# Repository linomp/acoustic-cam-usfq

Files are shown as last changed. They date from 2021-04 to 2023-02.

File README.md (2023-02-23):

# Sound Visualization with an Acoustic Camera

This is the source code repository for the project "Sound Visualization with an Acoustic Camera", my Mechanical Engineering undergraduate thesis at USFQ (Ecuador).

The thesis explains the process of building an [acoustic camera](https://felixtrument.ca/acoustic-camera-all-you-need-know/), from the design of the microphone array to the integration of the required software layers. 

A National Instruments data acquisition card and LabView were used to record the signals of an array of 16 condenser microphones simultaneously, while the open source library [Acoular](http://www.acoular.org/) was used to process the signals, applying beamforming techniques. 

The result was a prototype of an acoustic camera capable of distinguishing and characterizing static sound sources in a frequency range from 2.8 kHz up to 6 kHz. 

## Resources
- [Download the full thesis here](https://repositorio.usfq.edu.ec/handle/23000/8978)
- [Check the project poster](https://github.com/linomp/acoustic_cam_usfq/blob/master/Poster.pdf)

## Index

1. [Installation](https://github.com/linomp/acoustic_cam_usfq#1-installation)
2. [Testing](https://github.com/linomp/acoustic_cam_usfq#2-testing)
3. [Performing new measurements](https://github.com/linomp/acoustic_cam_usfq#3-performing-new-measurements)
4. [Notes](https://github.com/linomp/acoustic_cam_usfq#4-notes)

## 1. Installation

### Python & Acoular
- [Anaconda with Python 3 support](https://www.anaconda.com/products/individual)
- [The acoular library (version 19)](https://pypi.org/project/acoular/19.2/)

  Make sure you go through their `Installation` and `Getting Started` sections to verify your installation is correct.
    
    After going through the [installation described here](http://www.acoular.org/install/index.html), you should be able to open the Anaconda prompt, type `python` to open the python interpreter, paste the following commands:
    
    ```python
    import acoular
    acoular.demo.acoular_demo.run()
    ```
    and you should get this result:
    
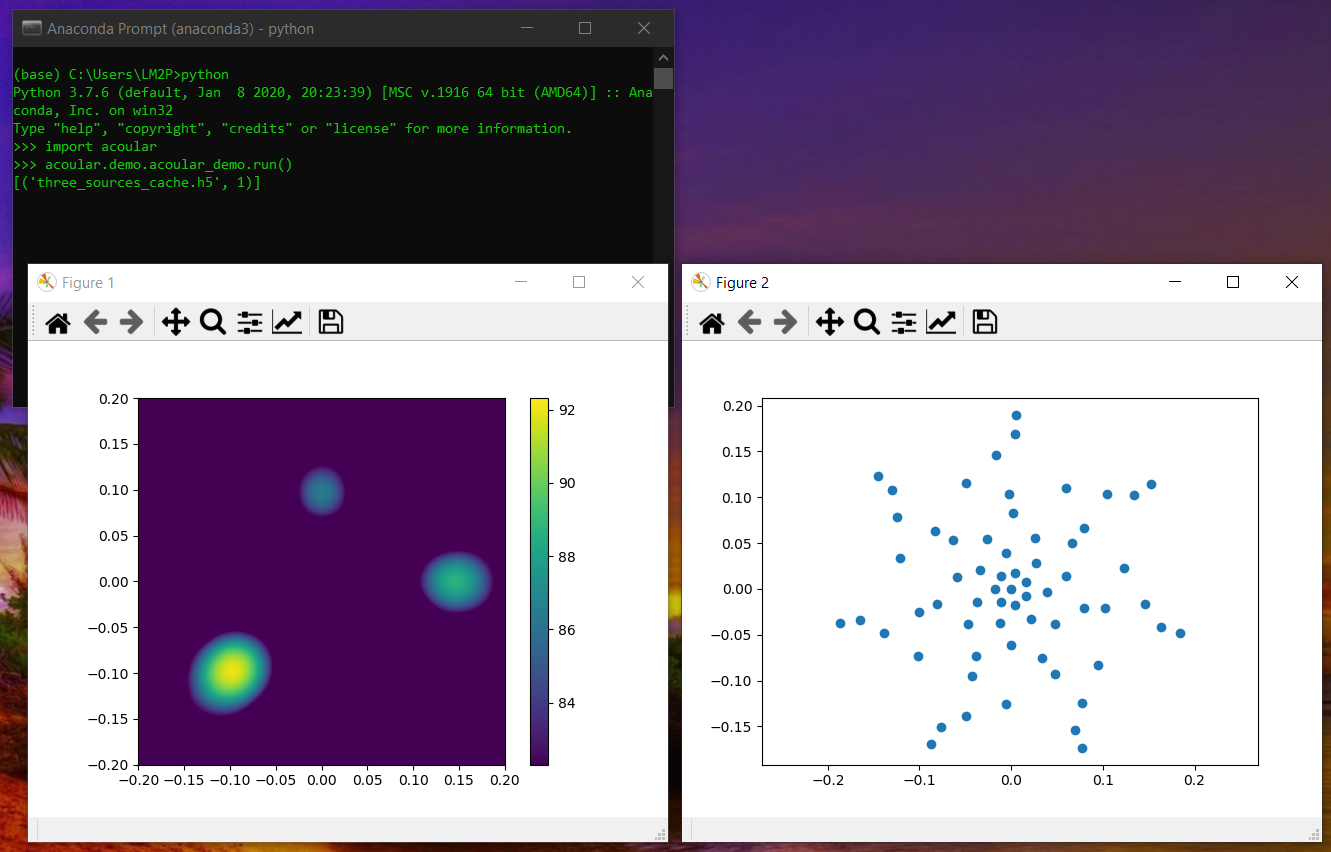
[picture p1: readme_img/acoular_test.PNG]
  

### LabView 
- [LabView 2017 SP1](https://www.ni.com/it-it/support/downloads/software-products/download.labview.html#306359) 
  - Note: uncheck the VI Package Manager 2017 option. You will be installing the latest version directly from their website, which works better.  
- [VI Package Manager (VIPM)](https://www.vipm.io/download/)
  - Note: after installing, hit the button that looks like a "refresh" icon to update the package repository so VIPM will work correctly.   

### LabView Packages
It is recommended to install these packages with VIPM, **in this exact order**:
- [OpenG Libraries](https://www.vipm.io/package/openg.org_lib_openg_toolkit/)   
- [LiveHDF by UPVI](https://www.vipm.io/package/lvhdf5/) ([documentation](http://www.upvi.net/main/index.php/products/lvhdf5))

At this point, your installed package listing should contain at least all these:

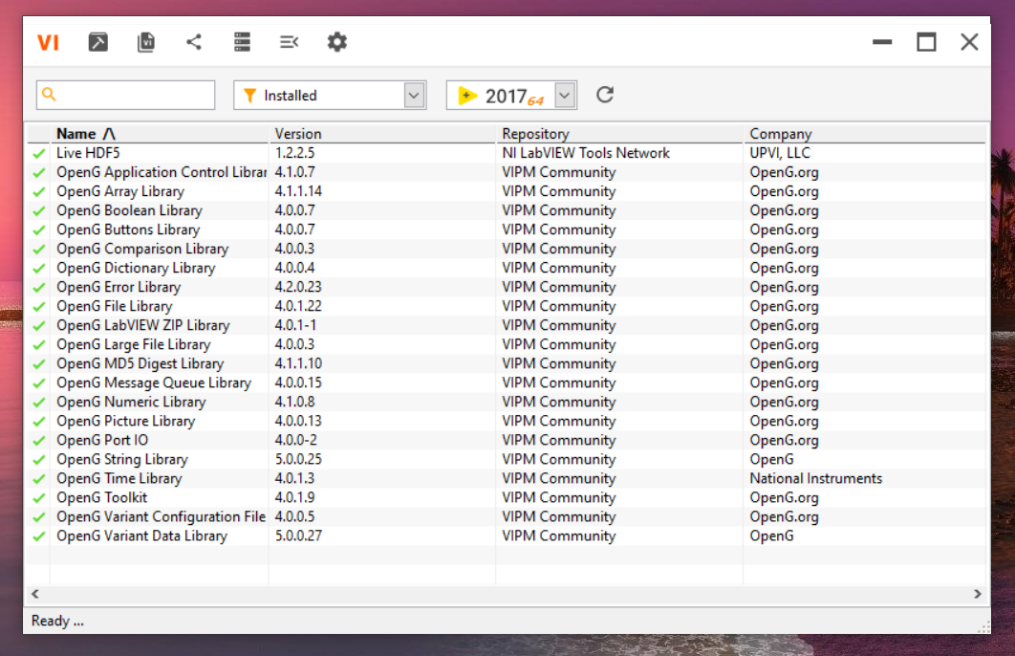
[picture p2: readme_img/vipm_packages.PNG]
  

These ones are installed from outside VIPM:
- [VAS](https://www.ni.com/en-us/support/downloads/drivers/download.vision-acquisition-software.html#367318) for LabView to webcam interfacing
- [NI DAQmx](https://www.ni.com/en-us/support/downloads/drivers/download.ni-daqmx.html#348669) for microphone data acquisition

### Optional tools
- [HDFView](https://www.hdfgroup.org/downloads/hdfview/) to inspect HDF5 files of your audio recordings and their metadata.
  - Note: If the program fails to launch, [try the solution mentioned here](https://portal.hdfgroup.org/display/support/HDFView+3.1.2#HDFView3.1.2-knownprobs). 
   
    To make the HDFViewApp-3.1.2 work on Windows 10 (64 bits), they ask you to download and paste the `hdfview.bat` file here:

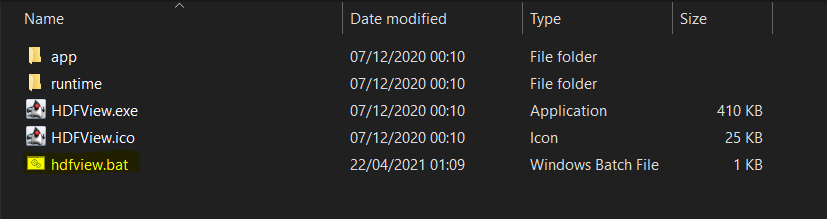
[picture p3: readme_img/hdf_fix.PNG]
      

    Then the app can be opened by double clicking on that `hdfview.bat` file.

## 2. Testing

To test your environment, an example measurement is provided. This includes an image and a white-noise recording in an hdf5 file.

- Open the project **`development_version/Beamforming_0_0_1.lvproj`**. In there open the VI called **`BeamformerGUI_GivenFreqs.vi`** and execute it.

- Switch from the `Measurement` tab to the `Processing` tab.
  
  - The Python server should be started in the background, give it some time. When the VI is ready to perform an analysis, it looks like this:
  
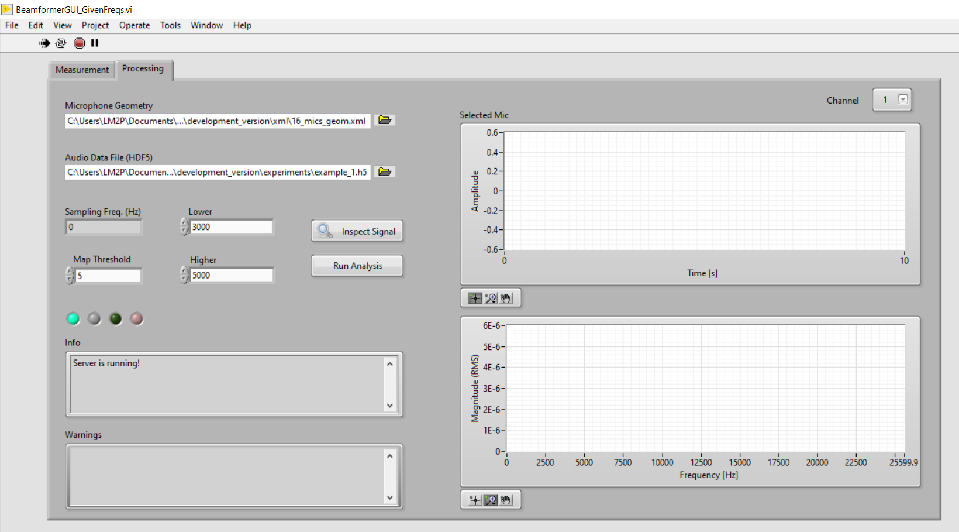
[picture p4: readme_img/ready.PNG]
     

  - By default, the VI already searches for the microphone geometry file `16_mics_geom.xml` in the `development_version/xml` folder. If you ever need to include another microphone geometry file, that is the place to add it.

  - For the `Audio Data File (HDF5)` option, make sure it points to: `development_version/experiments/example_1.h5` (should be done by default too, but please double check).
  
    - Inspecting it with HDFView:
    
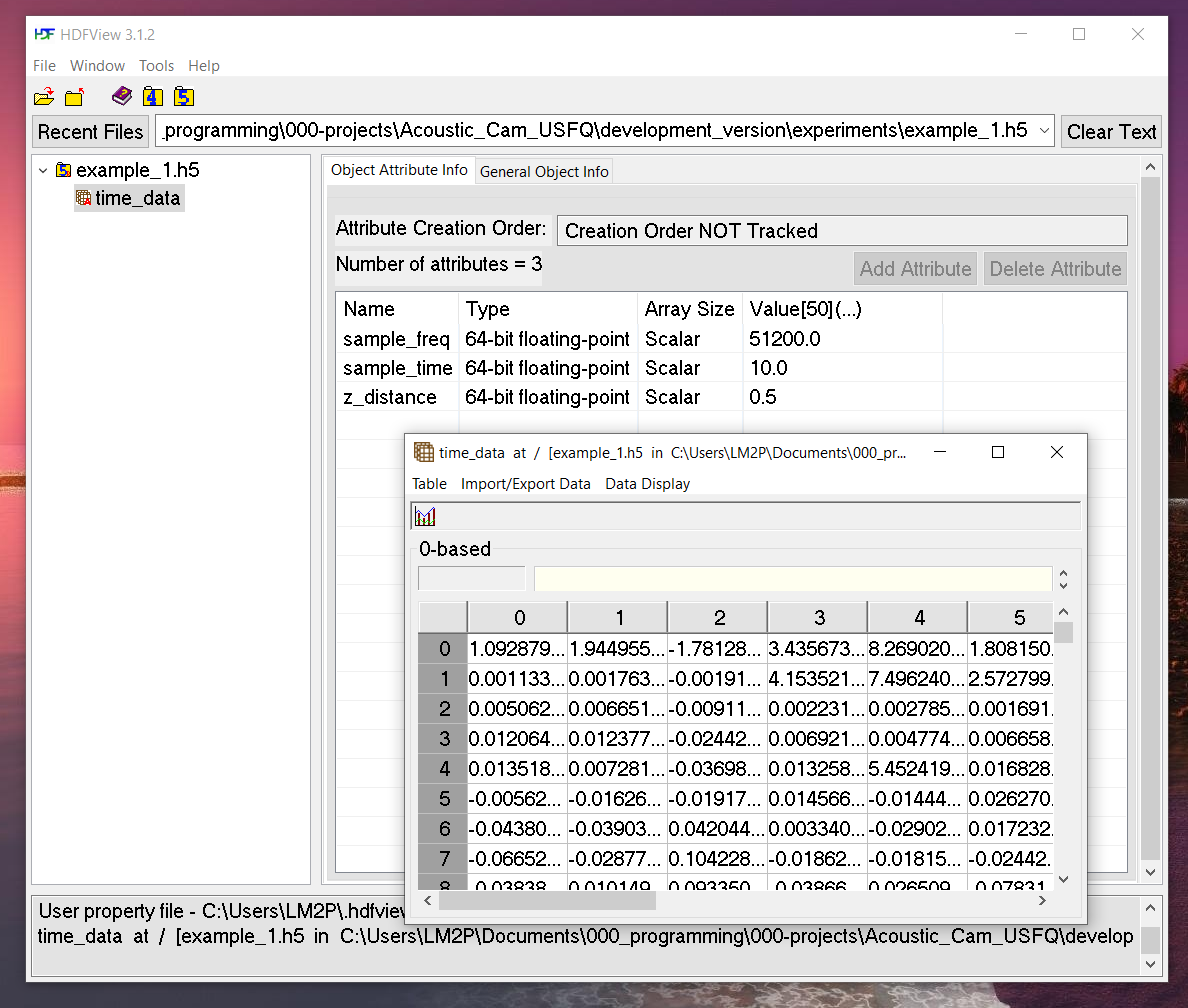
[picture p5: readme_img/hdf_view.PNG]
      
    
    - Inspecting it with the `Inspect Signal` function:
  
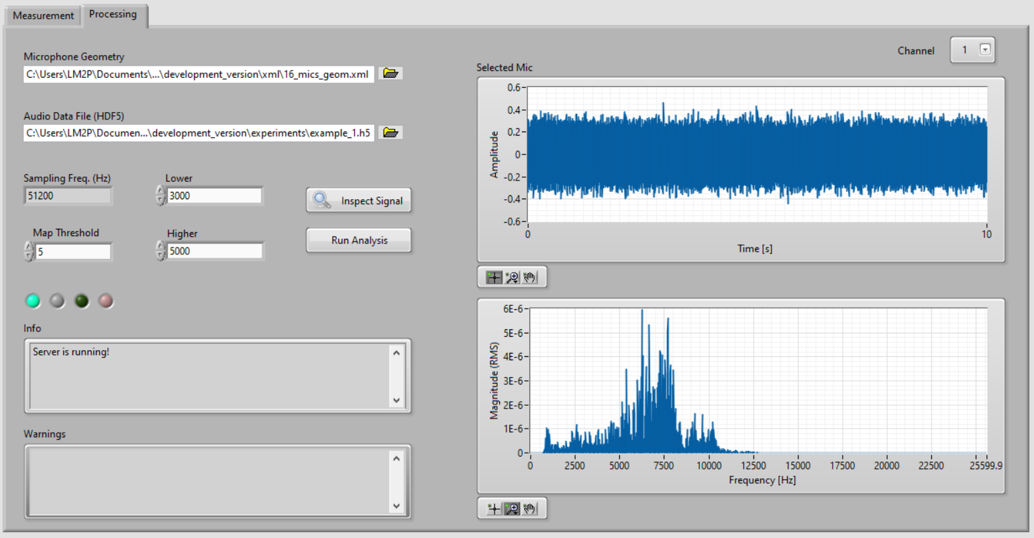
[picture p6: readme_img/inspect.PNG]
      

    - Click on `Run Analysis` and you should get this message:
  
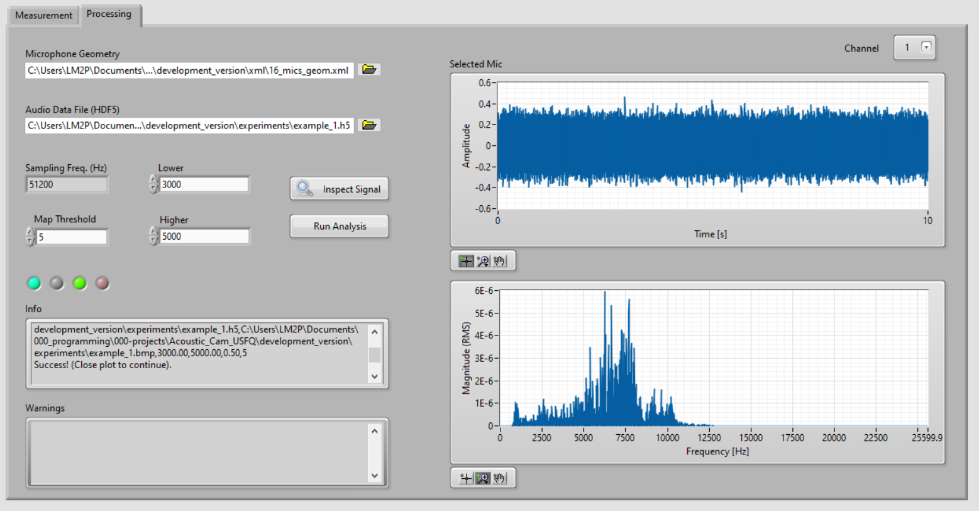
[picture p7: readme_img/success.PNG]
      

      And the following plot:

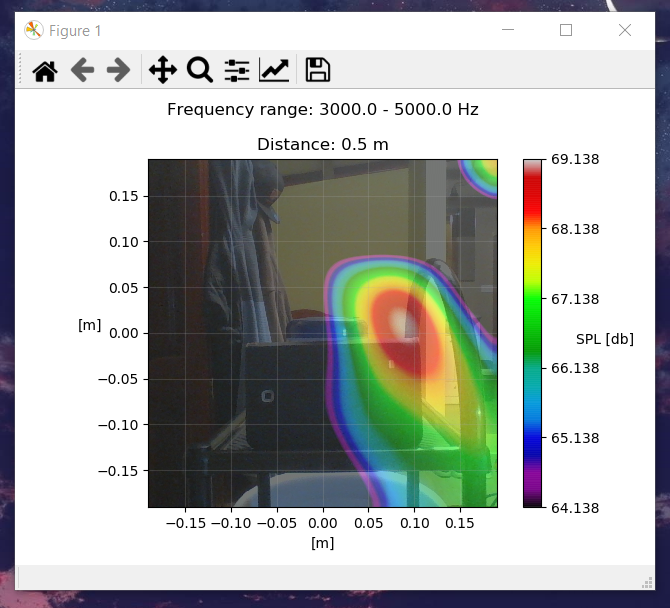
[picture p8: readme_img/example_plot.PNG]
      

## 3. Performing New Measurements

**Tip:** read the [Final Report](https://github.com/linomp/acoustic_cam_usfq/blob/master/Final%20Report.pdf) for information about best-performing parameters.

- In the `Measurements` tab, you can use the `Preview Signals` button to check the status of the microphones:

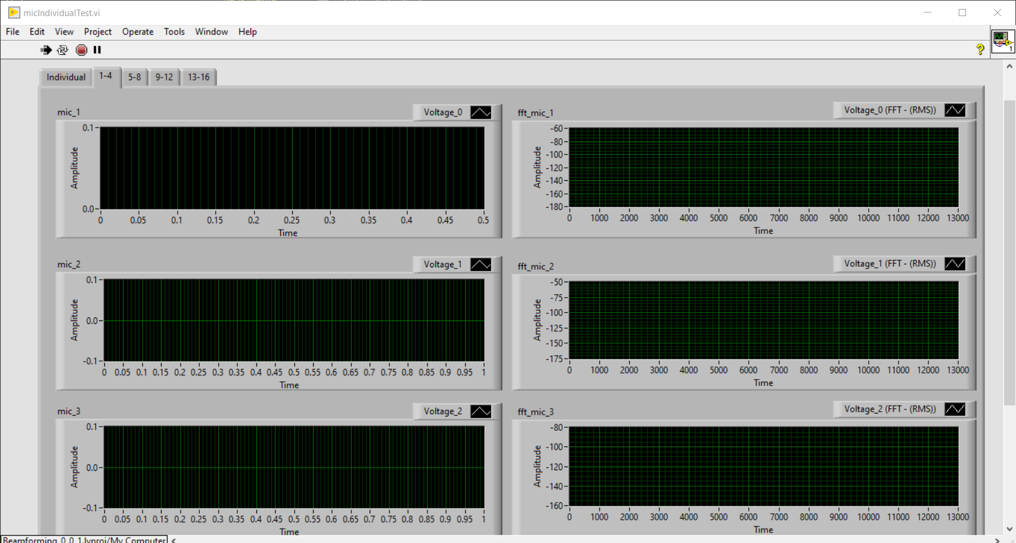
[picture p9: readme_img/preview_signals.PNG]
  

- Select the camera device.
- Focus the camera to the desired object/scenario to analyze.
- Select the data directory.
- Input a name for the experiment (will be used both for the audio recording and the image).  
- Input the distance in [m] from the array to the sound source.
- Input a sampling time and a sampling frequency. 
  - Note: Take into account that the hardware has its sampling rate limitations. Also, theoretically the sampling frequency has to be at least twice the maximum frequency in the signal you wish to analyze (see [Nyquist Theorem](http://microscopy.berkeley.edu/courses/dib/sections/02Images/sampling.html) / [Recommended Video](https://www.youtube.com/watch?v=yWqrx08UeUs)).  
- Click record and wait.
- After recording, the GUI should look like this:
  
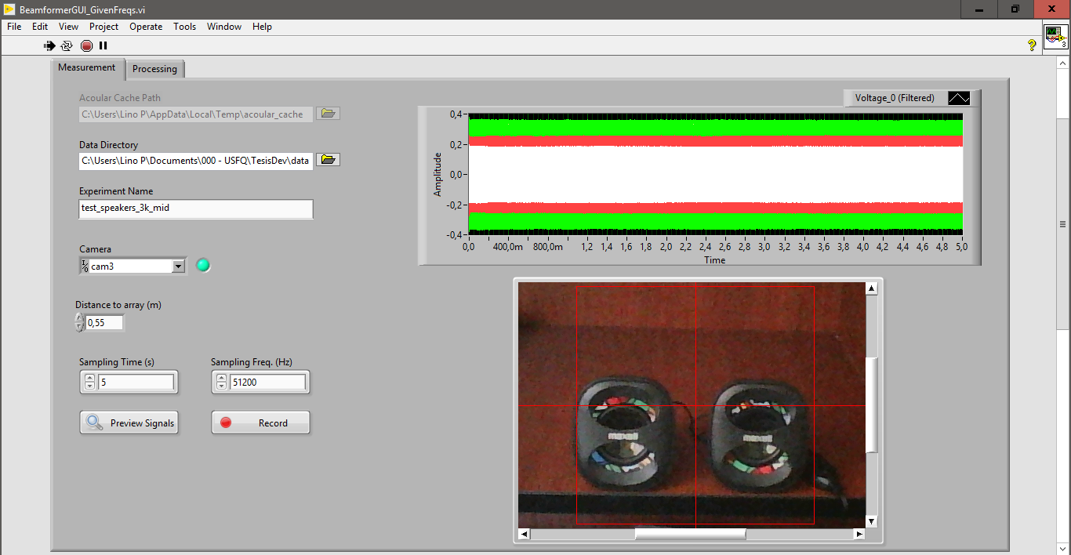
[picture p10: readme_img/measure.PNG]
   

- Switch to the `Processing` tab. It will already be pointing to the newly created data file. There you can `Inspect` the signal or `Run   Analysis` immediately, like in the previous section.

- The `Lower` and `Higher` parameters determine the beggining and start of the frequency range to be taken into account for the actual acoustic map.

## 4. Notes
- The VI measurement feature cannot be performed without the Data Acquisition board already connected and configured.  

- There might be setup and or additional driver installation required when connecting the Data Acquisition board. 
  
  Locate this section of the `BeamformerGUI_GivenFreqs.vi` block diagram and open the `DAQ Assistant` to configure your hardware:

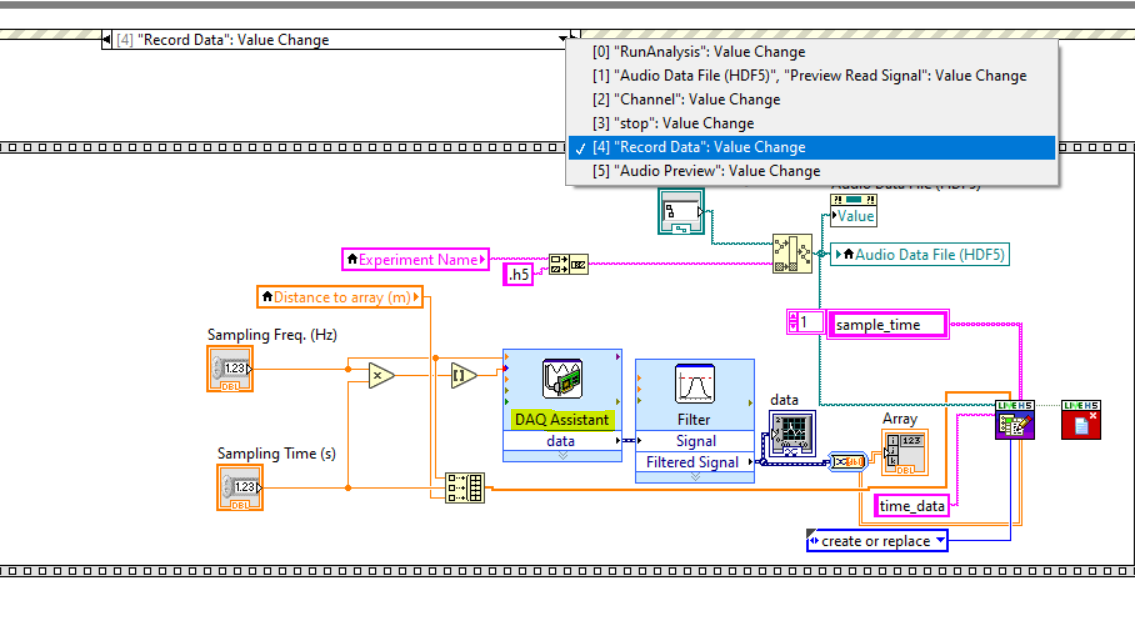
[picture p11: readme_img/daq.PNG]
   

- The calibration file location is currently `/development_version/xml/ECM8000_07_09_19_01.xml` and this is hard-coded in the `development_version/py/beamforming.py` file. Take this into account if you need to provide a different file.

- Take note of the `Acoular Cache Path` in the `Measurement` tab. Acoular saves previous results there to optimize performance but you might need to manually clear the contents of that folder if you want to analyze new measurements with a same filename you used previously.

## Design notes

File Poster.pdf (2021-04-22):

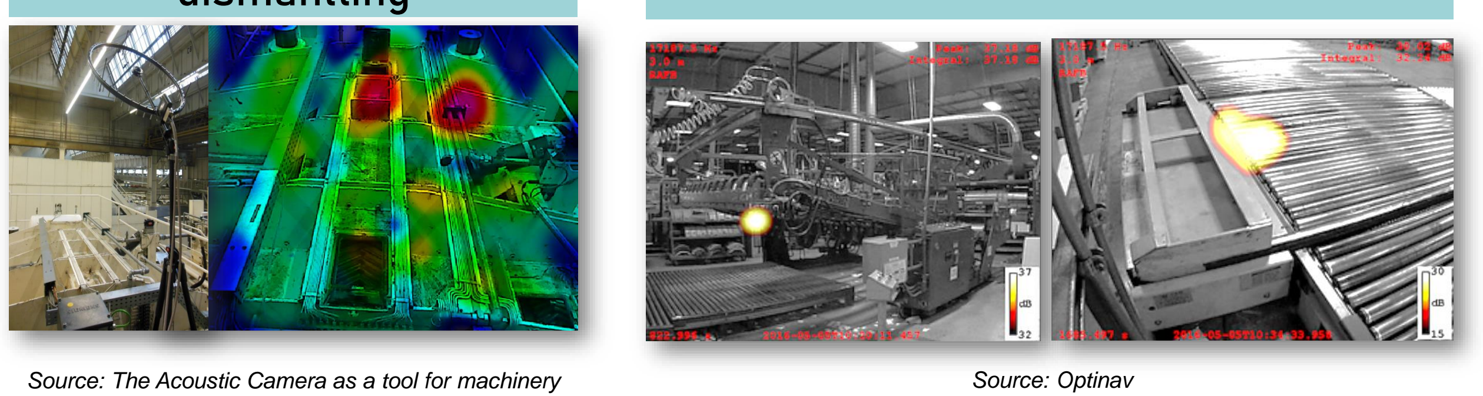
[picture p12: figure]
Source: Optinav
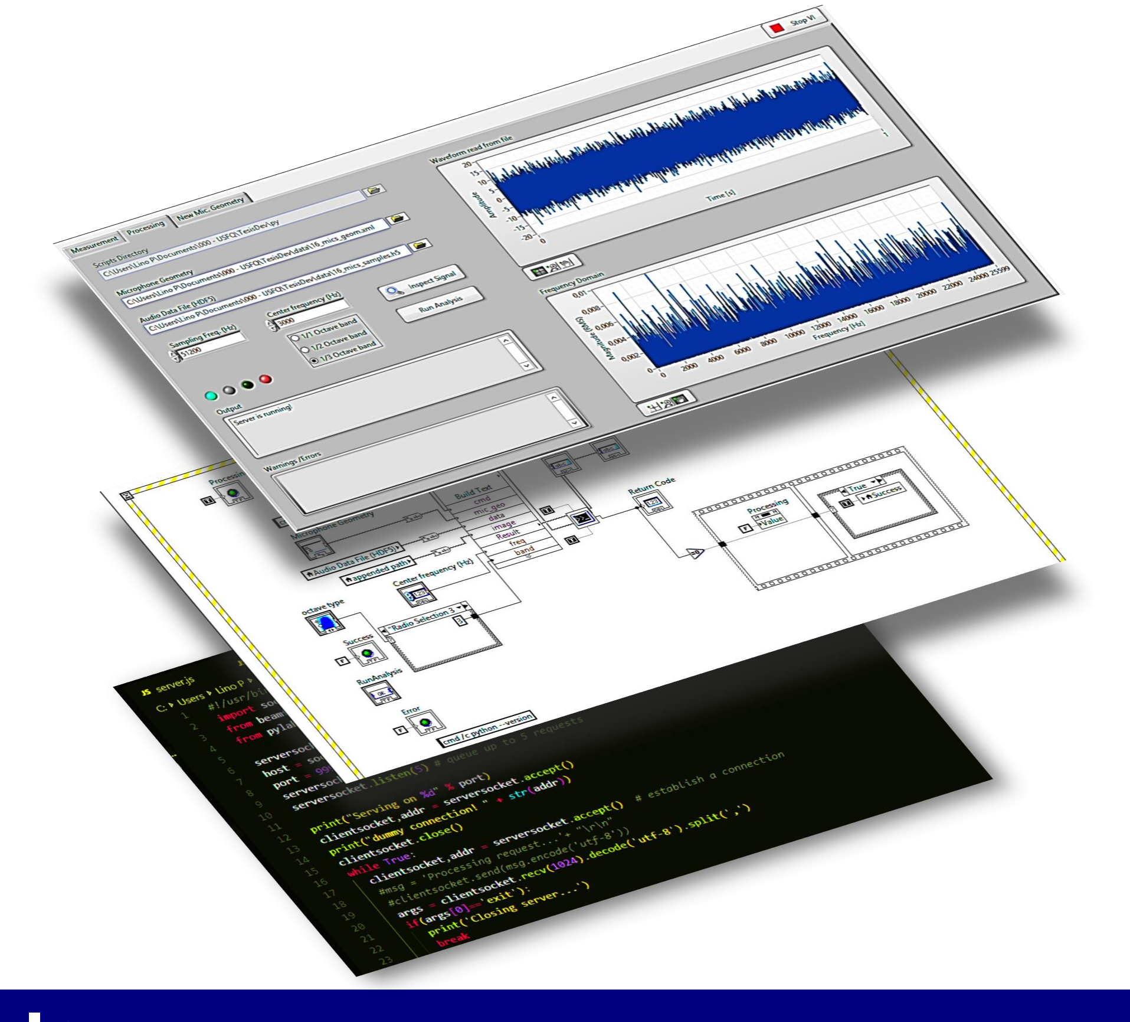
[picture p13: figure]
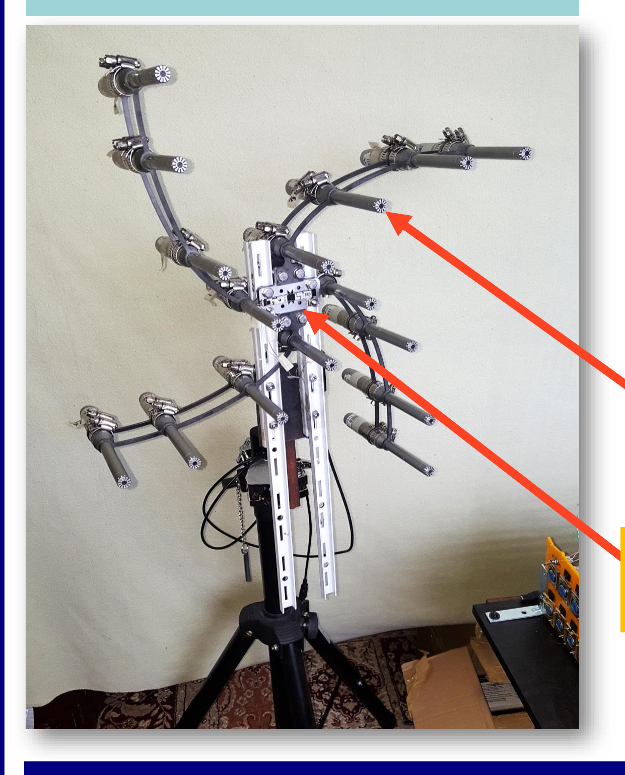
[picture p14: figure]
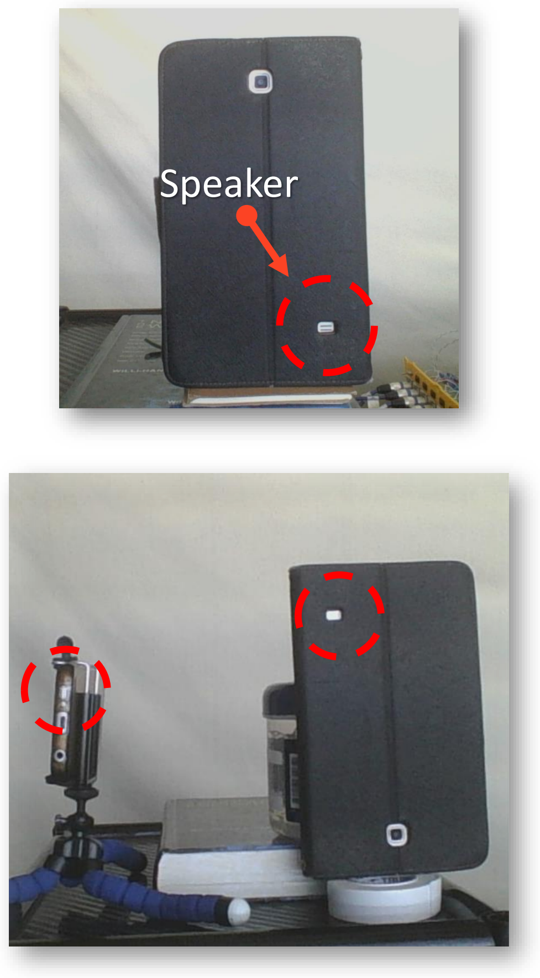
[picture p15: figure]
Speaker
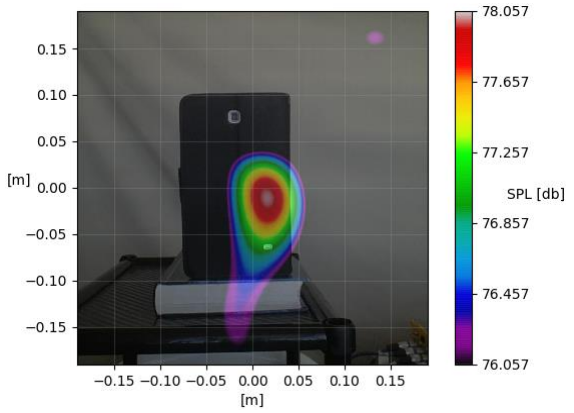
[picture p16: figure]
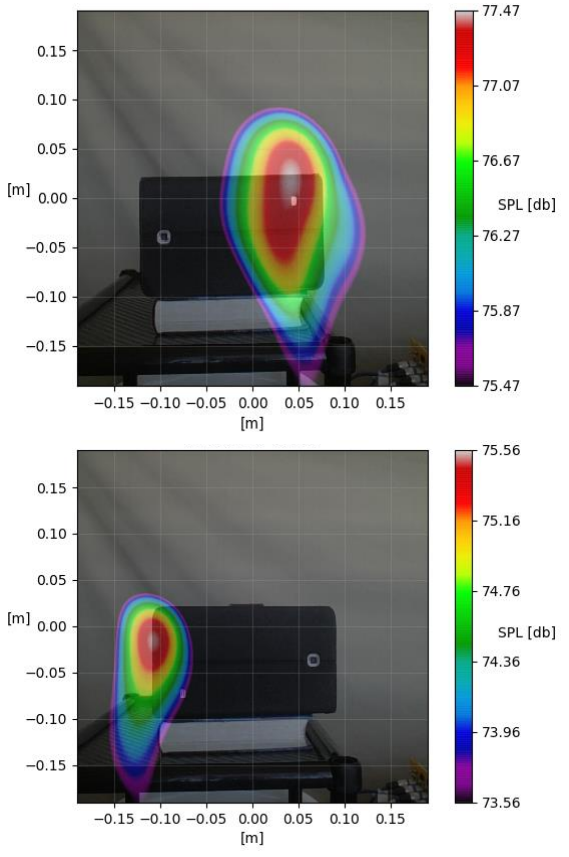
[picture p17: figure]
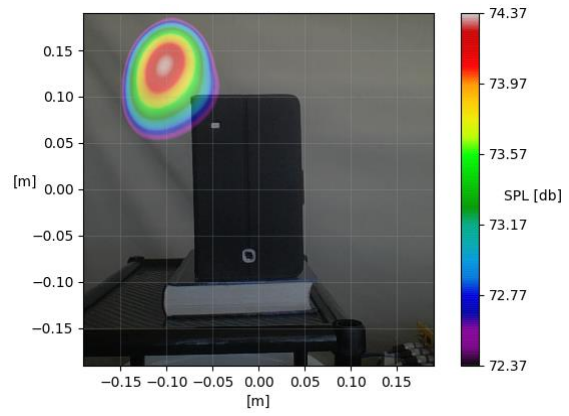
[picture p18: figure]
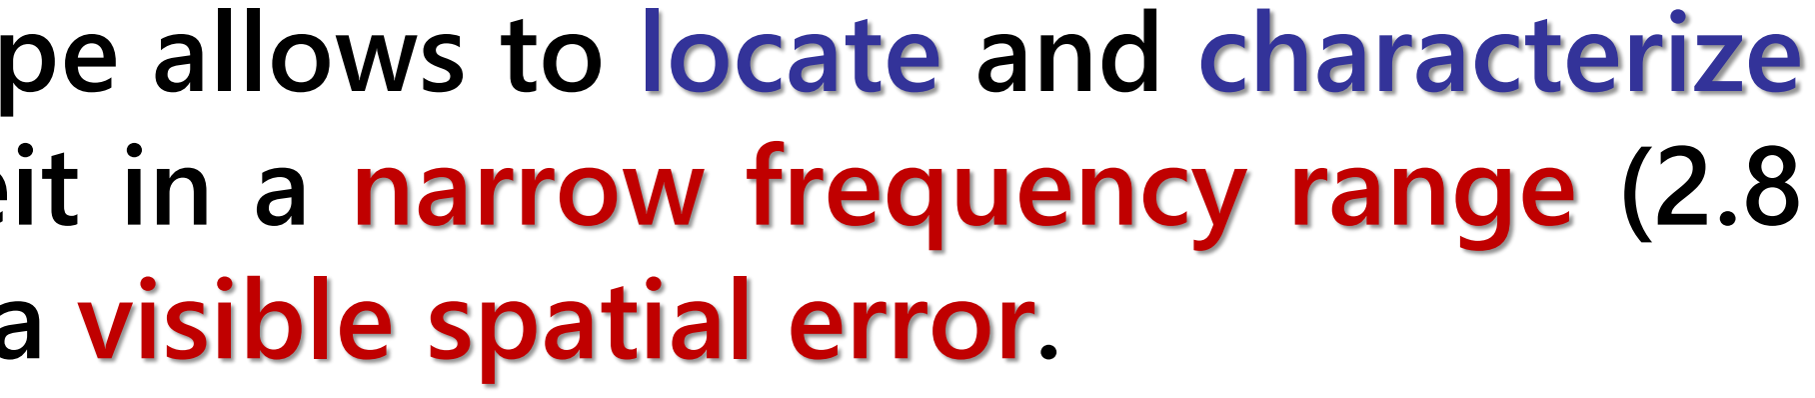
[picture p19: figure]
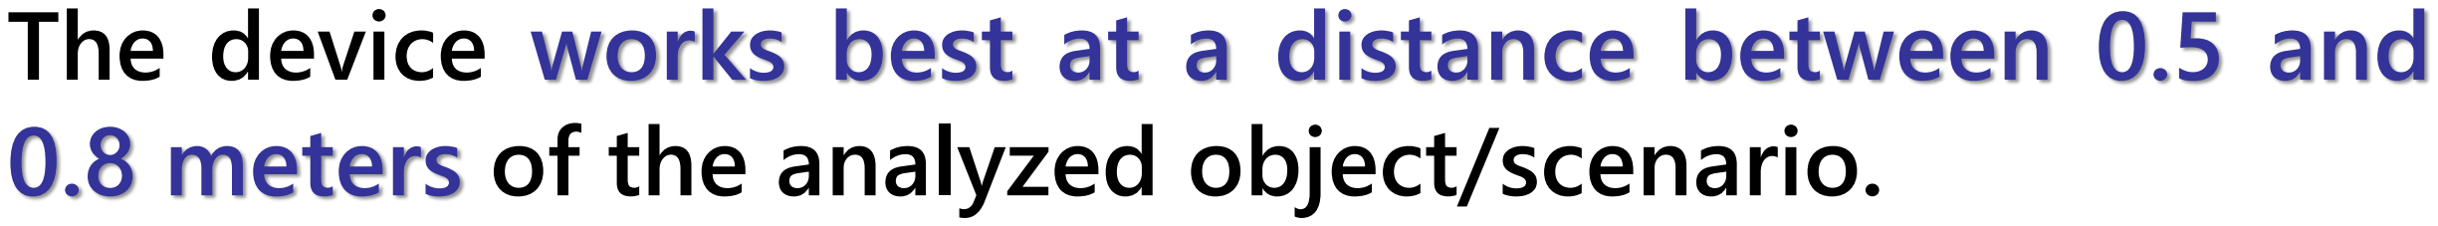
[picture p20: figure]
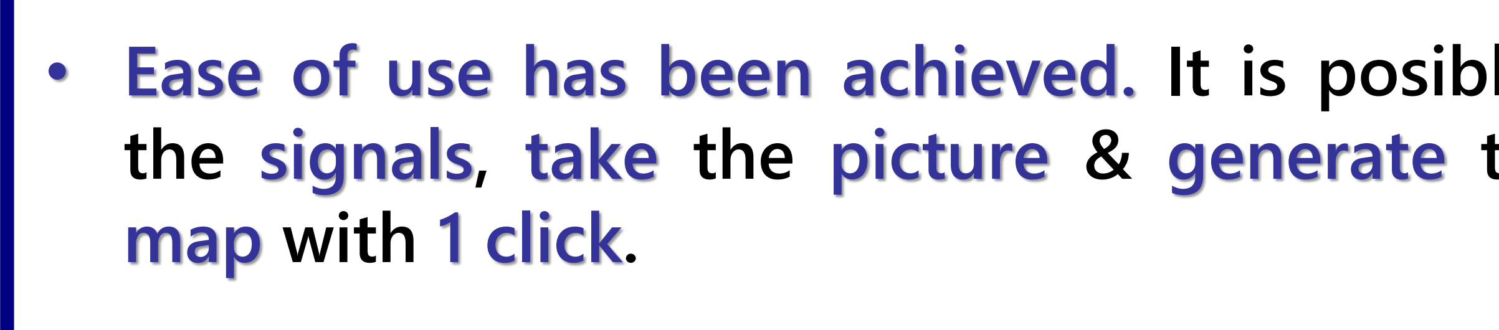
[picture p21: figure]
map with 1 click.
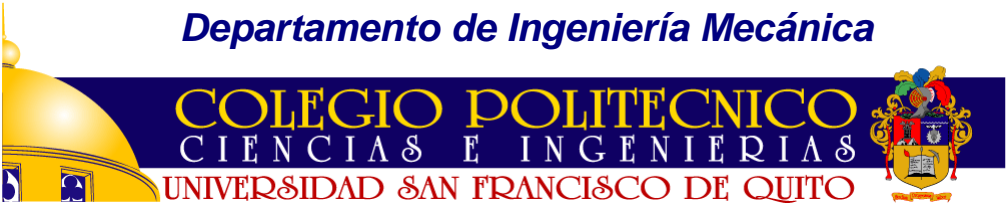
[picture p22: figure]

Departamento de Ingeniería Mecánica | Clase:
| Autores:

# Sound Visualization with an Acoustic Camera

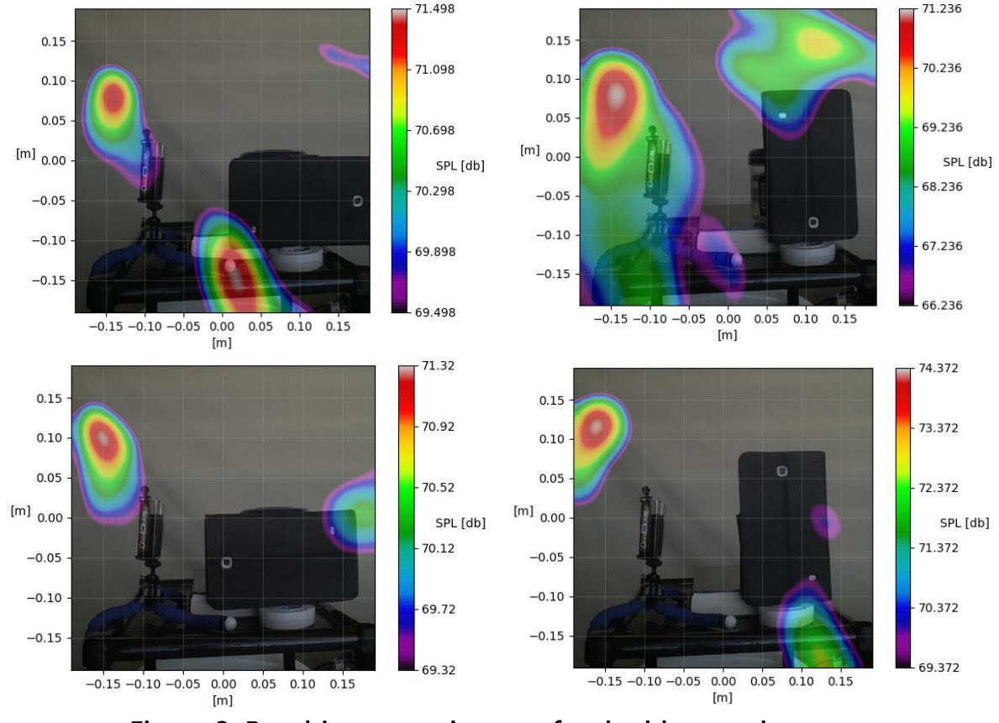
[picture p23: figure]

UICTT – Desarrollo de Trabajo de Titulación

Lino Mediavilla Ponce

## Conclusions

Hardware Components | Software Layers

## Motivation

Universidad San Francisco de Quito Feria de Ingeniería Mecánica XXV
Quito, 28 de noviembre de 2019

## Results

## Room for improvement

Behringer

ECM-8000

NI cDAQ

9178

Webcam

Microphone Array | Data Acquisiton Card

LabView 2017

Processing

Python server
+
Acoular
Beamforming
library v19.01

User Interface

- The current prototype allows to locate and characterize sound sources, albeit in a narrow frequency range (2.8 to 6 kHz), and with a visible spatial error.
- The device works best at a distance between 0.5 and 0.8 meters of the analyzed object/scenario.
- Ease of use has been achieved. It is posible to record the signals, take the picture & generate the acoustic
- A higher ‘unique intra-sensor spacing ratio’ (F parameter) in the array would lower spatial aliasing effects thus expanding the working frequency range of the device. (current F parameter is 0.2, the ideal is 1).
- Ensure the correct alignment of microphones and camera. Discrepancies between the sensor positions passed to the program and the actual positions can greatly affect results.
Single Sound source (White Noise) | Two sound sources (White Noise)

Figure 1. Resulting acoustic maps for single sound source test.

(Distance: 0.5 m, Freq. Range: 3000- 5000 Hz)

- Current solution for sound pressure measurements: SPL meters (point by point).
- Acoustic cameras enable us to “see” sound, i.e. to analyze entire areas at once & characterize unknown sources.

Compressed air leak detection

Diagnosis without
dismantling

Source: The Acoustic Camera as a tool for machinery maintenance (Böck, 2015).

Figure 2. Single and double

sound source test setup.

Figure 3. Resulting acoustic maps for double sound source test.

(Distance: 0.5 m, Freq. Range: 3000- 5000 Hz)

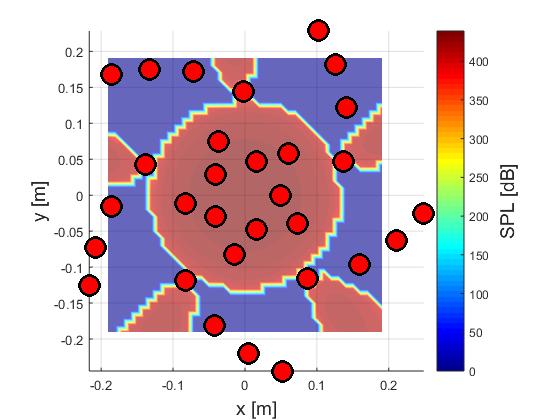
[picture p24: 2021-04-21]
development_version/postProc/30_mics_PSF_w.bmp

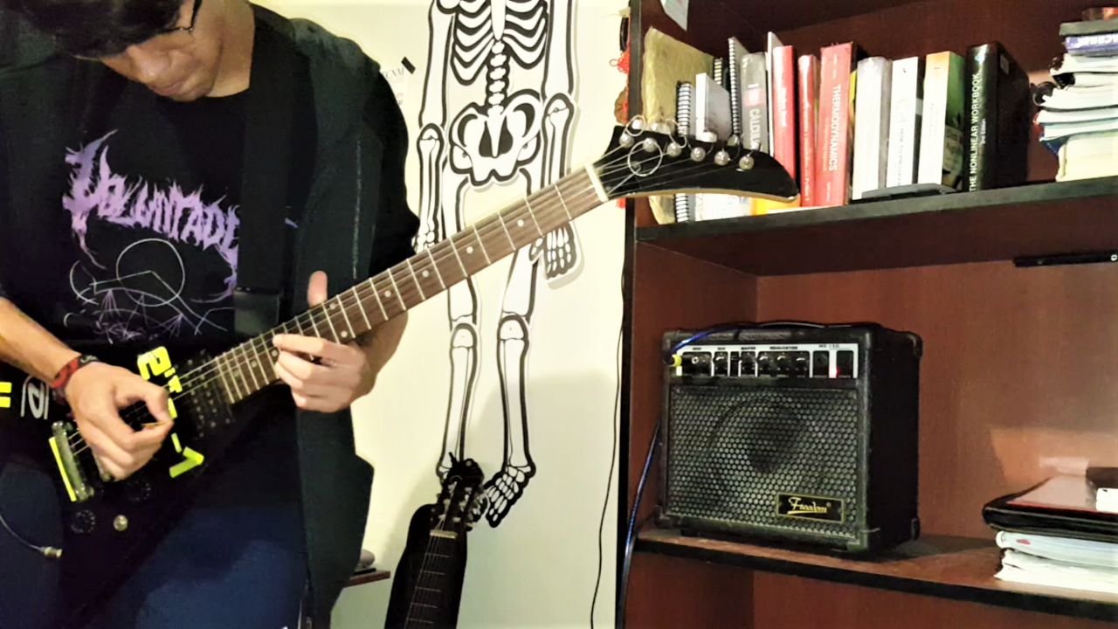
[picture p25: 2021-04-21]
development_version/postProc/gtr.png

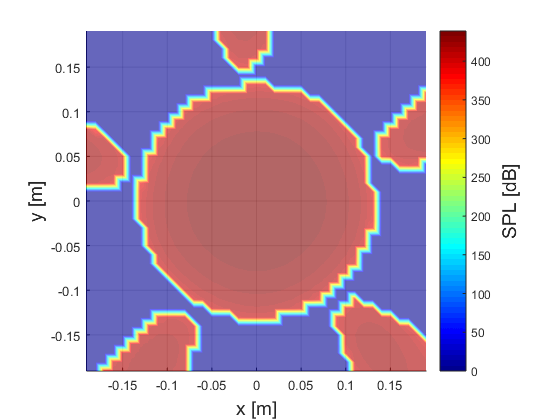
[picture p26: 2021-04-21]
development_version/postProc/30_mics_PSF.bmp

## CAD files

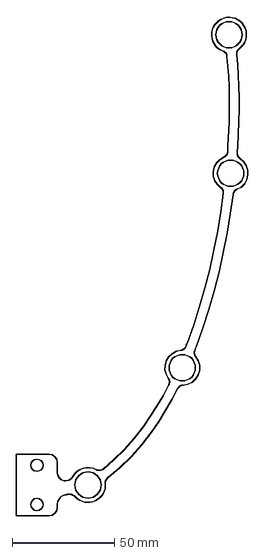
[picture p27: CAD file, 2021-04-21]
development_version/ipt/new_arm_front.dxf
113.4 x 243.9 mm

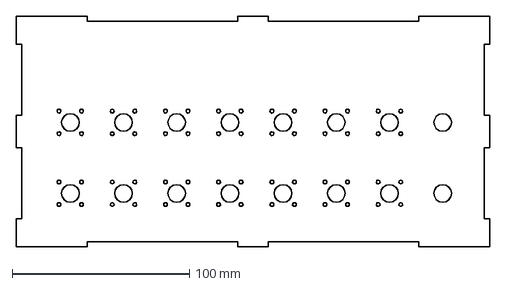
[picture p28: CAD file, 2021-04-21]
development_version/ipt/case_back.dxf
267.0 x 130.2 mm

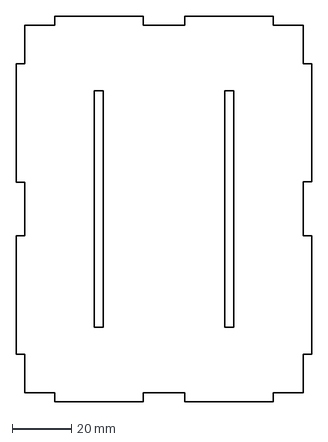
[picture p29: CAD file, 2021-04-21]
development_version/ipt/case_side.dxf
100.0 x 130.2 mm

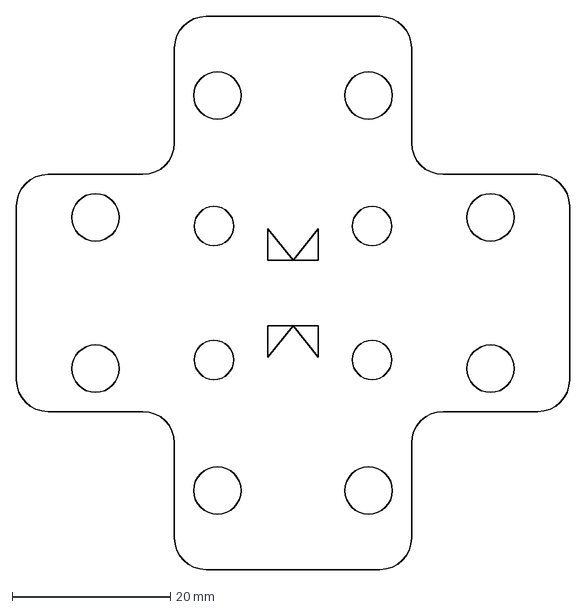
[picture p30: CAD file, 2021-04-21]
development_version/ipt/new_base.dxf
70.0 x 70.0 mm

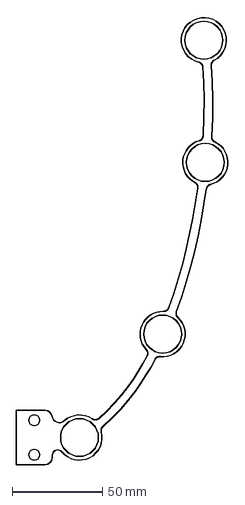
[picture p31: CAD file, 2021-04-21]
development_version/ipt/arm_back.dxf
117.6 x 248.1 mm

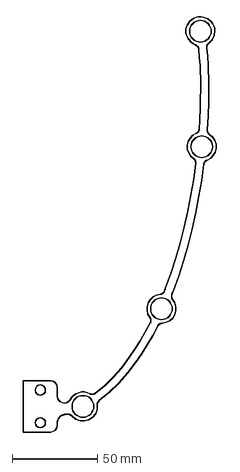
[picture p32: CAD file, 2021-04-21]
development_version/ipt/arm_front.dxf
113.4 x 243.9 mm

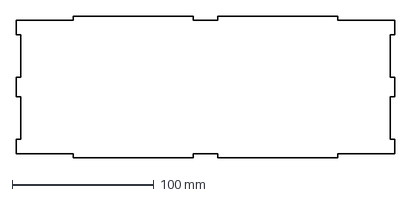
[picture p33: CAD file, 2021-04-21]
development_version/ipt/case_top.dxf
267.0 x 100.0 mm

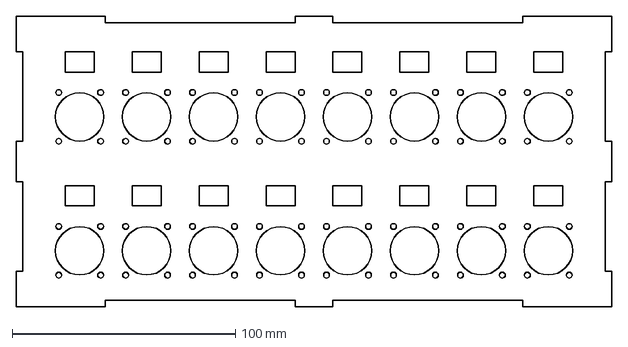
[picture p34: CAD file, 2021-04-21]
development_version/ipt/case_front.dxf
267.0 x 130.2 mm

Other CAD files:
development_version/ipt/OldVersions/back_plate.0006.ipt
development_version/ipt/OldVersions/back_plate_2.0001.ipt
development_version/ipt/OldVersions/case_asm.0023.iam
development_version/ipt/OldVersions/case_back.0010.ipt
development_version/ipt/OldVersions/case_base.0002.ipt
development_version/ipt/OldVersions/case_front.0006.ipt
development_version/ipt/OldVersions/case_roof.0003.ipt
development_version/ipt/OldVersions/case_roof.0008.ipt
development_version/ipt/OldVersions/case_side.0006.ipt
development_version/ipt/OldVersions/case_side_A.0005.ipt
development_version/ipt/OldVersions/case_side_B.0003.ipt
development_version/ipt/OldVersions/front_plate.0009.ipt
development_version/ipt/OldVersions/front_plate_2.0002.ipt
development_version/ipt/OldVersions/underbrink_arm_lite_2.0020.ipt
development_version/ipt/OldVersions/underbrink_arm_lite_2_bigDiam.0009.ipt
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

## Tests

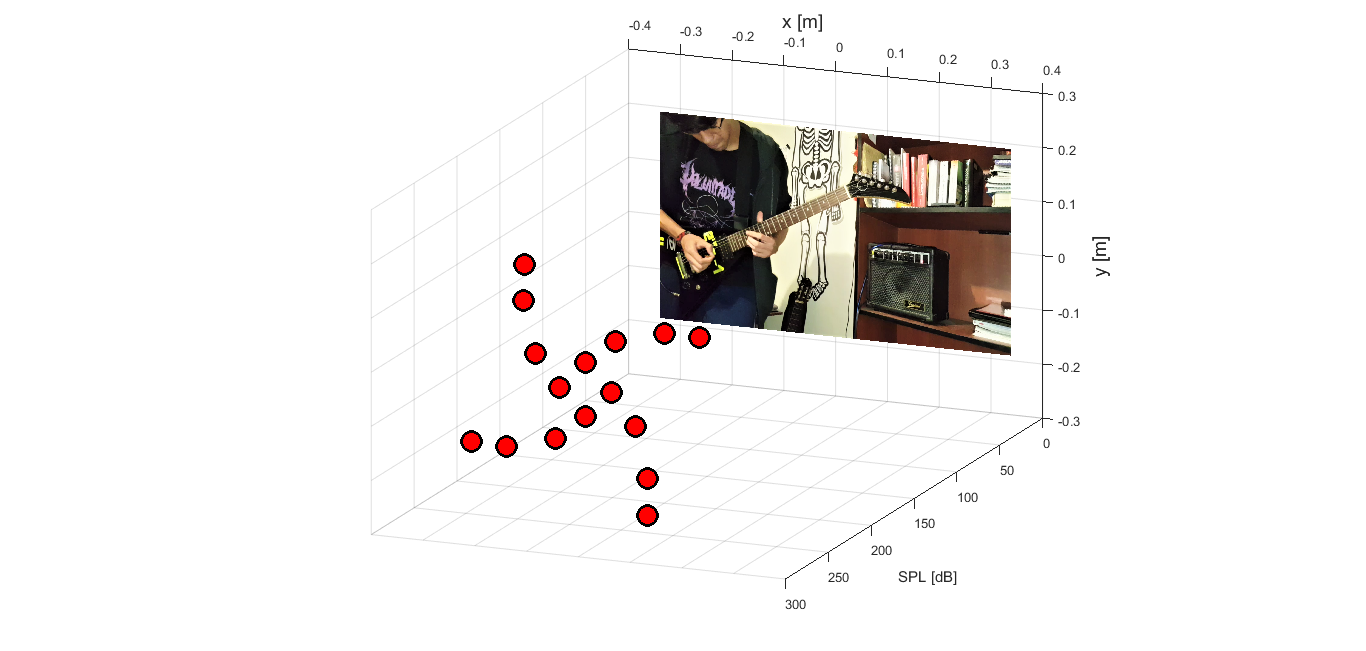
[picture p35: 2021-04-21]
development_version/postProc/visualsTestNoSurf.bmp

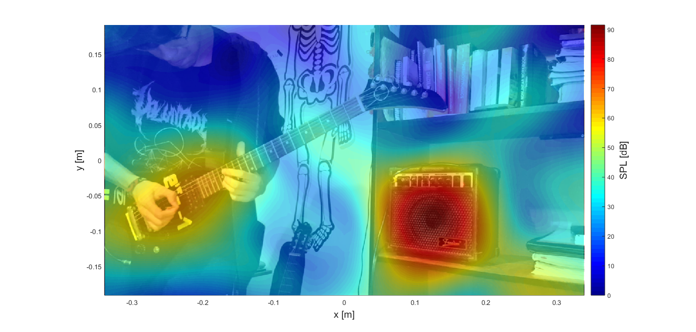
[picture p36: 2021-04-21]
development_version/postProc/result.bmp

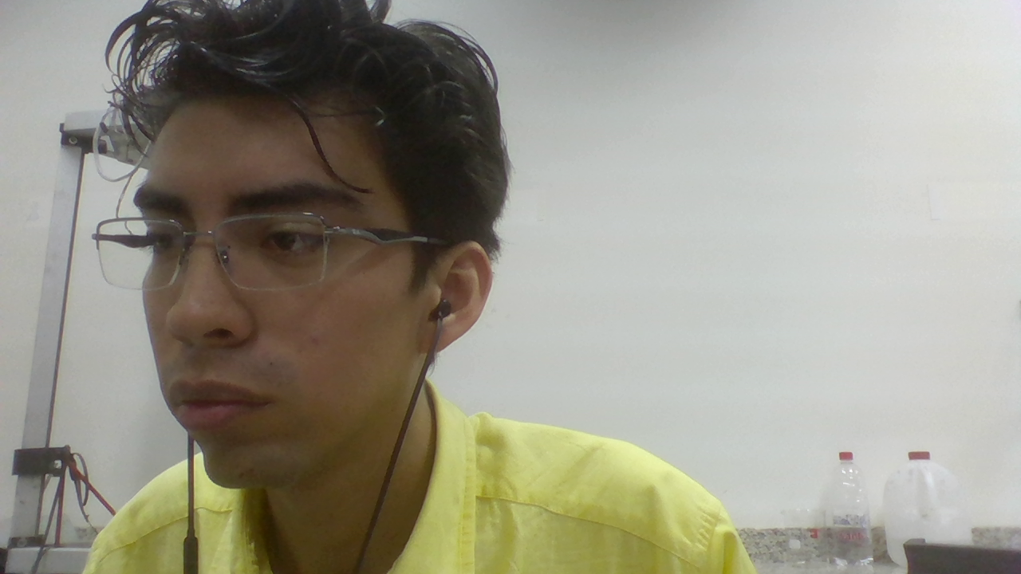
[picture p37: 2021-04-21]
development_version/postProc/test2.bmp
